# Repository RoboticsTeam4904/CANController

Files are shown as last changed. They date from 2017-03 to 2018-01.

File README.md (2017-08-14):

### CANController
This is a KiCAD file for a PCB that converts the serial bus data from sensors to CAN bus data using an intermediary embedded Teensy 3.2 which are then passed through DB15 connectors and VGA cables to other similar PCBs (other board schematics can be found in different repositories on github.com/roboticsteam4904).
The main sensors are LiDAR and encoders but it can be used with most sensors that have more than 5-pin connections. It also functions as power and data signal for LED strips scuh as the Adafruit Neopixels.

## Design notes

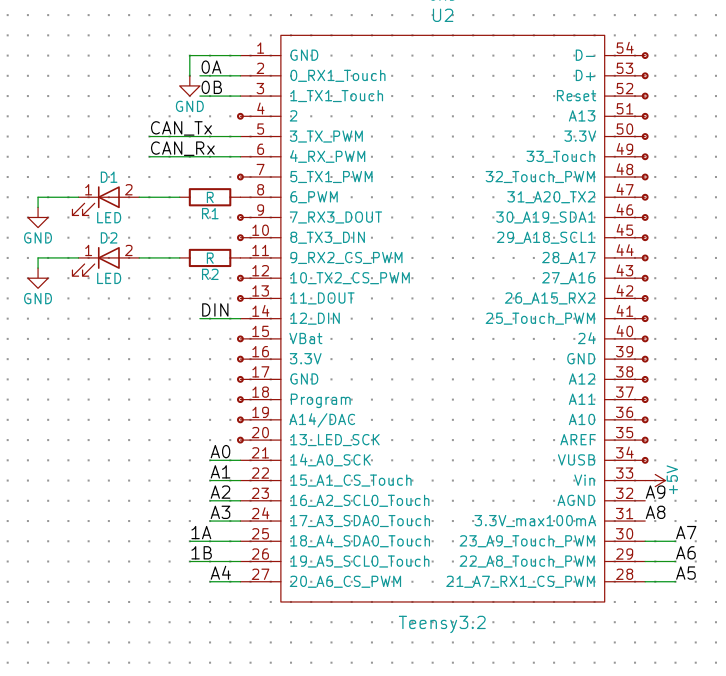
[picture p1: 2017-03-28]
reference/MerittsBoard_Pinouts.png

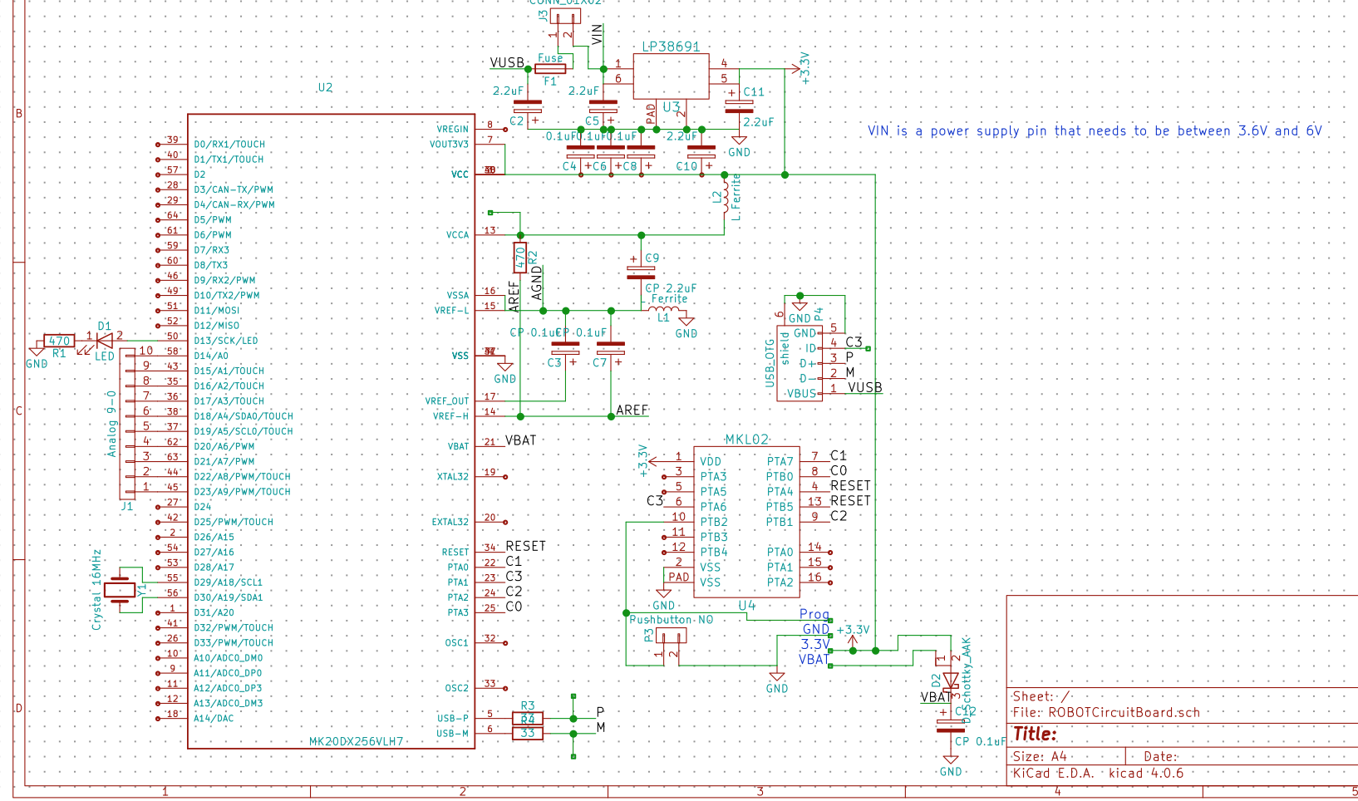
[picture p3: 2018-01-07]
reference/Screen Shot 2018-01-07 at 10.27.42 AM.png

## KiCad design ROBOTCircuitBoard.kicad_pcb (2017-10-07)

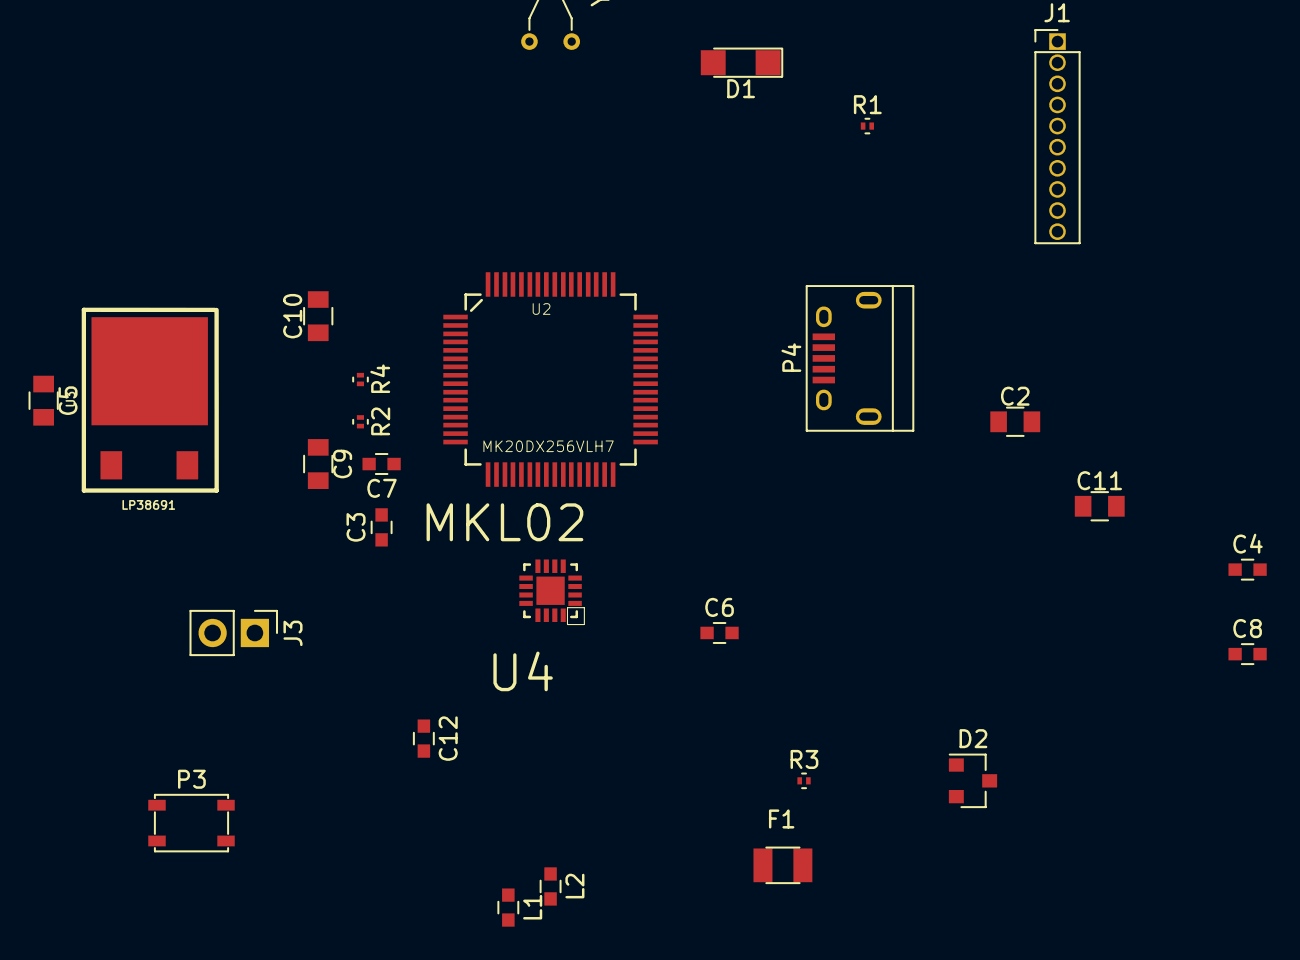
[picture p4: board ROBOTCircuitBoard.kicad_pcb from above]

Board: 2 copper layers, 28 parts (0 on the bottom side), 34 nets, no tracks yet.

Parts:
C2, C5, C10, C11: 2.2uF; C_0805
C3, C7, C12: CP 0.1uF; C_0603
C4, C6, C8: 0.1uF; C_0603
C9: CP 2.2uF; C_0805
D1: LED; LED_1206
D2: D_Schottky_AAK; D_SOT-23_ANK
F1: Fuse; Fuse_SMD1206_Reflow
J1: Analog 9-0; Socket_Strip_Straight_1x10_Pitch1.27mm
J3: CONN_01X02; Pin_Header_Straight_1x02_Pitch2.54mm
L1, L2: L Ferrite; C_0603
P3: Pushbutton NO; SW_SPST_PTS810
P4: USB_OTG; USB_Micro-B
R1, R2: 470; R_0201
R3, R4: 33; R_0201
U2: MK20DX256VLH7; QFP50P1200X1200X160-64N
U3: LP38691; lp38691
U4: MKL02; Teensy_DIY_v1.0-QFN50P300X300X100-17N
Y1: Crystal 16MHz; Crystal_AT310_d3.0mm_l10.0mm_Horizontal

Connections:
+3V3: C11.1, D2.2, L2.1, U2.3, U2.7, U2.30, U2.48, U4.1
/AGND: C3.2, C7.2, C9.2, L1.1, U2.15, U2.16
/AREF: C7.1, R2.2, U2.14
/C0: U2.25, U4.8
/C1: U2.22, U4.7
/C2: U2.24, U4.9
/C3: P4.4, U2.23, U4.6
/M: P4.2, R4.2
/P: P4.3, R3.2
/RESET: U2.34, U4.4, U4.13
/VBAT: C12.1, U2.21
/VIN: C5.2, J3.2, U3.1
/VUSB: C2.2, F1.2, P4.1
GND: C2.1, C4.2, C5.1, C6.2, C8.2, C10.2, C11.2, C12.2, L1.2, P3.2, P4.5, P4.6, R1.2, U2.4, U2.31, U2.47, U3.2, U4.2
unnamed: C3.1, U2.17
unnamed: C9.1, L2.2, R2.1, U2.13
unnamed: D1.1, R1.1
unnamed: D1.2, U2.50
unnamed: F1.1, J3.1
unnamed: J1.1, U2.45
unnamed: J1.2, U2.44
unnamed: J1.3, U2.63
unnamed: J1.4, U2.62
unnamed: J1.5, U2.37
unnamed: J1.6, U2.38
unnamed: J1.7, U2.36
unnamed: J1.8, U2.35
unnamed: J1.9, U2.43
unnamed: J1.10, U2.58
unnamed: P3.1, U4.10
unnamed: R3.1, U2.5
unnamed: R4.1, U2.6
unnamed: U2.55, Y1.1
unnamed: U2.56, Y1.2

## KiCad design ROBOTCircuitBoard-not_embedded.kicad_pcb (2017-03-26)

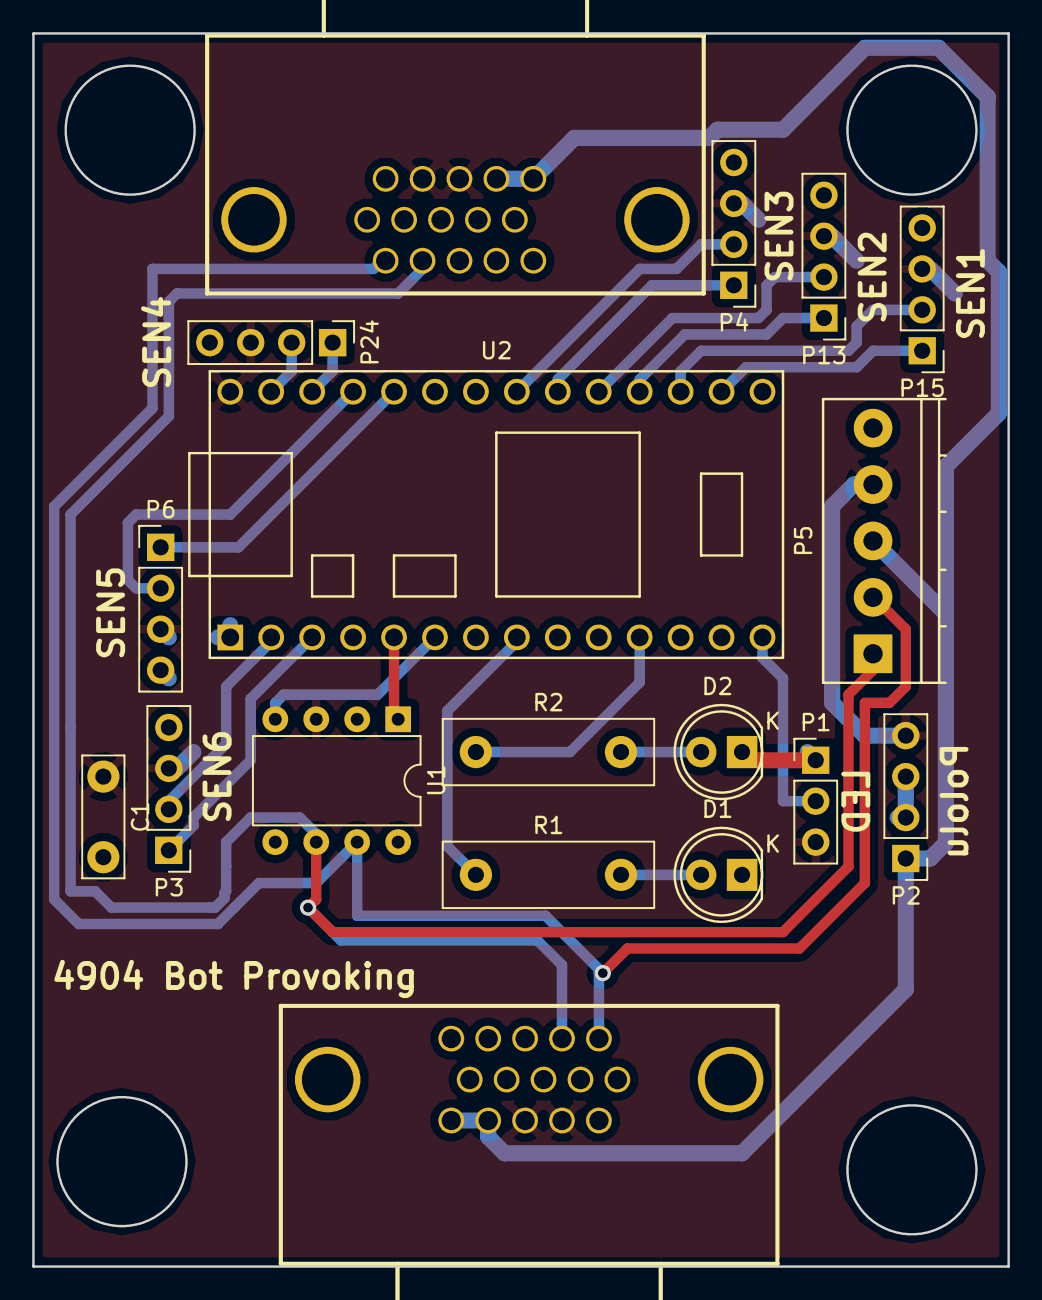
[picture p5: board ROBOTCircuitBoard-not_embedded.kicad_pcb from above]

Board: 2 copper layers, 60.5 x 76.5 mm, 18 parts (0 on the bottom side), 24 nets.

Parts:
C1: C; C_Disc_D7.5mm_W2.5mm_P5.00mm
D1, D2: LED; LED-5MM
J1, J2: DB15_HighDensity_MountingHoles; conn_SPC15430
P1: CONN_01X03; Socket_Strip_Straight_1x03_Pitch2.54mm
P2, P3, P4, P6, P13, P15, P24: CONN_01X04; Socket_Strip_Straight_1x04_Pitch2.54mm
P5: CONN_01X05; TerminalBlock_Pheonix_PT-3.5mm_5pol
R1, R2: R; R_Box_L13.0mm_W4.0mm_P9.00mm
U1: MCP2551-I/P; DIP-8_W7.62mm
U2: Teensy3.2; Teensy30_31_32_LC_LessPins

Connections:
+5V: C1.1, J1.12, J1.13, J2.12, J2.13, P1.3, P2.4, P3.3, P4.3, P5.4, P6.3, P13.3, P15.3, P24.3, U1.3, U2.33
+12V: J1.14, J1.15, J2.14, J2.15, P2.1, P5.3
/0A: P3.2, U2.2
/0B: P3.1, U2.3
/1A: P4.1, U2.25
/1B: P4.2, U2.26
/A0: P15.1, U2.21
/A1: P15.2, U2.22
/A2: P13.1, U2.23
/A3: P13.2, U2.24
/A6: P6.1, U2.29
/A7: P6.2, U2.30
/A8: P24.1, U2.31
/A9: P24.2, U2.32
/CANH: J1.1, J2.1, P5.2, U1.7
/CANL: J1.2, J2.2, P5.1, U1.6
/CAN_Rx: U1.4, U2.6
/CAN_Tx: U1.1, U2.5
/DIN: P1.2, U2.14
GND: C1.2, D1.1, D2.1, J1.6, J1.7, J1.8, J1.9, J1.10, J2.6, J2.7, J2.8, J2.9, J2.10, P1.1, P2.2, P2.3, P3.4, P4.4, P5.5, P6.4, P13.4, P15.4, P24.4, U1.2, U1.8, U2.1
unnamed: D1.2, R1.2
unnamed: D2.2, R2.2
unnamed: R1.1, U2.8
unnamed: R2.1, U2.11

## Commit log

2017-03-26 Connected main chip and bootloader
    [ROBOTCircuitBoard.sch]
2017-03-26 Made that shitty footprint slightly better
    [ROBOTCircuitBoard.sch]
2017-03-28 Added reference folder with images
    [ROBOTCircuitBoard.sch]
2017-06-03 worked more on the teensy
    [ROBOTCircuitBoard.sch]
2017-07-18 Labled a button
    [ROBOTCircuitBoard.sch]
2017-07-18 added the crystals
    [ROBOTCircuitBoard.sch]
2017-07-25 fixing things more
    [ROBOTCircuitBoard.sch]
2017-07-25 Added more components
    [ROBOTCircuitBoard.sch]
2017-07-31 Fixed standardization and other issues
    Made grounds point downwards for standardization
    Fixed an issue with AREF and AGND not being on either side of a capacitor
    Fixed some incorrectly placed traces and labels
    [ROBOTCircuitBoard.sch]
2017-08-01 added the lp38691
    [ROBOTCircuitBoard.sch]
2017-08-01 finished schematic draft 1
    [ROBOTCircuitBoard.sch]
2017-08-02 Fixed capacitor, organization, and VIN issues Fixed issues with pins 4 and 5 on the LP38691 not being connected to 3.3VDC becuase of capacitor Took out long traces and reorganized Made a VIN trace fo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
    [ROBOTCircuitBoard.sch]
2017-08-13 Added LED and renamed incorrectly named files Added an LED for debugging purposes Renamed ROBOTCircuitBoard.kicad_pcb to ROBOTCircuitBoard-not_embedded.kicad_pcb because it is the same as a previous 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
    [ROBOTCircuitBoard-not_embedded.kicad_pcb, ROBOTCircuitBoard.sch]
2017-08-13 Why the heck does this bother me so much? The README looks half-decent now so I can die in peace. Thanks for hating me markdown.
2017-08-15 Began annotations and added dual shottkey Began annotation of schematic Added a two inpput one output shottkey diode instead of two diodes going to VBUS
    [ROBOTCircuitBoard.sch]
2017-08-15 Replaced jumper with 1X02 connector Replaced jumper with 1X02 connector for ability to manually determine which voltage source to use (using an external jumper cable) in case of misaligned voltages
    [ROBOTCircuitBoard.sch]
2017-08-29 isolated the teensy
    [ROBOTCircuitBoard.sch]
2017-09-01 added footprint libraries
2017-09-01 made a lp38691 footprint
    [ROBOTCircuitBoard.kicad_pcb, ROBOTCircuitBoard.sch]
2017-09-22 added libraries
    [ROBOTCircuitBoard.sch]
2017-09-29 finished the component libraries
    [ROBOTCircuitBoard.kicad_pcb, ROBOTCircuitBoard.sch]
2017-09-30 updated netlist, soread out objects
    [ROBOTCircuitBoard.kicad_pcb, ROBOTCircuitBoard.sch]
2017-10-07 moved something
    [ROBOTCircuitBoard.kicad_pcb]
2018-01-07 adding kicad screenshot of scematic
